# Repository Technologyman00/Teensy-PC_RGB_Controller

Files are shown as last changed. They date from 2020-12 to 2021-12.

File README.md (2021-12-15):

# Teensy-PC_RGB_Controller
 
The whole Idea behind this project was to create a much better RGB controller than the controllers or motherboard software I have seen. Currently It has already met that goal as it can play any pattern for many LEDs and up to individual 40 devices. I am still working on the user interface and many qualities of life things, but the main functionality does work. HOWEVER, it will need a PCB made to power all the LEDs as a Teensy cannot power that many safely.

## Features

- No Extra load on the CPU. The teensy has its own built in CPU that will handle all the commands to the ARGB devices.
- Store Loads of Patterns or Huge animations. The teensy uses an SD card to save and read all the patterns allowing for a huge number of patterns to be saved.
- Up to 40 ports. Most Controllers top out at a maximum of 4 ports. The teensy has 40! This allows each device to do its own individual pattern.
- Any pattern! There are no limitations on what can be displayed because it plays back frames allowing an almost infinite amount of customization. 
- Standard Plugs! This uses the regular 3 pin 5V ARGB connectors so any device with the same connector can be used!
- OPEN SOURCE! Are you a bit handier than most? You can change anything you would ever what about this project!

## Documentation
### Pattern Files

Description | Command | Argument 1 | Argument 2
------------ | -------------| ------------ | -------------|
Send RGB Command: | 0 | Port Number | Color Data |
Send HSV Command: | 1 | Port Number | Hue (2 Bytes) S (1 Byte) V (1 Byte)|
Change Frame Delay: | 2 | Delay (2 Bytes) | N/A |
Create Device/Change Length: | 3 | Port Number | Number of Pixels |
Start New Frame: | 4 | N/A | N/A | N/A |

- Port 13 is not accessable from the hardware as it has the status LED so it was intentionally skipped in the PCB design. 

- Color Data is a continuous set of the RGB or HSV values. It will be (3 * Number of Pixels in Device) bytes long. For example it would go (Red Byte)(Blue Byte)(Green Byte)(Red Byte)(Blue Byte)(Green Byte)... or (Hue Byte)(Saturation Byte)(Value Byte)(Hue Byte)(Saturation Byte)(Value Byte)... All these bytes are from 0-255 with no decimals, as bytes are. For hue, saturation, and value these are all scaled to their corrective values.

- The delay value is split into 2 different bytes to allow a delay between 0 and 65535ms or 65.5 seconds. This allows a great range between quick animations and still colors. This value does not matter so much for still colors as the pattern file will just start over once it reaches the end re-displaying the same color.

### Serial Commands

Description | Command | Argument 1 | Argument 2 | Argument 3 |
------------ | -------------| ------------ | -------------| -------------|
Play File on SD Card: | P | File Name | N/A | N/A |
Write File to SD Card: | W | File Name | Length to Read (4 Bytes) | File Data |
Delete File on SD Card: | X | File Name | N/A | N/A |
List Files on SD Card: | L | N/A | N/A | N/A |
Change Startup File: | S | File Name | N/A | N/A |
Display Frame: | D | RGB or HSV -> (0 or 1) | Port Number | Color Data |
New Device: | N | Port | Number of Pixels | N/A |
Restart Teensy: | R | N/A | N/A | N/A |
Check Teensy Tempature: | T | N/A | N/A | N/A |

- File Name requires the file type *"example.txt"*
- File Data follows the documentation as setup in pattern files
- Length to Read is split into 4 bytes to allow very large files to be transferred (~4.3 GB) (if larger than ~4.3 GB just put the file onto the SD card manually)
- Color Data also follows the documentation as shown in pattern files
- ***Deleting files will ask if "Are sure you want to delete this?" A response is needed of Y/N before it will continue. Everything is halted when this is prompted.***
- ***Showing a Frame will not return to normal file reading until an exit command of X is sent.***

### Startup Handler

On startup the teensy will first read the *startup.txt* file which should contain the name of the file and only the name of the file. If this file does not exist or the code is unhappy with what was entered it will delete the *startup.txt* file and replace it with a *startup.txt* file that will run the default pattern file. The default pattern file sets all 40 ports to display Green on 255 pixels on those ports. This should make it so that it is obvious that the Teensy is working. The *startup.txt* file can be changed by either editing the file in a text editor or by sending the S command over serial.

## Updates
6/6
Full Deployment!!!!!
Example 1: https://youtu.be/utrNA2Hu2Kg
Example 2: https://youtu.be/6SqUPKUgLiA

5/30 Version 2 of the PCB was ordered and should be arriving shortly. This new version is to fix the concerns with the previous version, as the size was quite large and there was a design error. Both should be fixed in this version. Pin 13 was also taken off of the available pins as it was decided that it should be used as a status LED and should remain off if used. 

3/14 PCB Came in had issues. The Output enable pin was grounded not powered, which means it was disabled not enabled. (Woops) A small soldered wire fixed that. 
First Test : https://youtu.be/IeGvDfm8C_M

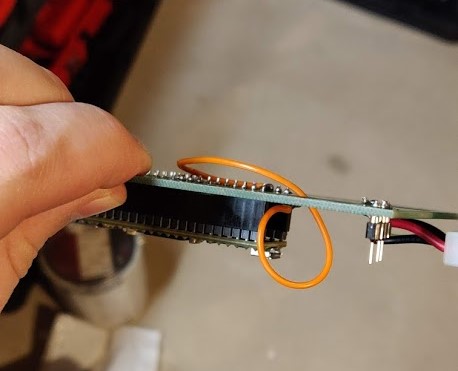
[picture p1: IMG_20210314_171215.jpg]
photo of wire added to PCB


## Limitations
#### Files
   - Limited to a File Name of 8 Characters
     - example1.txt is at the max length
   - Is not case-sensitive 
     - example1.txt == EXAMPLE1.txt
      
#### Max SD card size is 32 GB
   - There are some potential work arounds for larger SD cards
   
#### LED Devices can only be added not removed per a given reboot
   - I really cant imagine this being an issue for anyone, but I thought its important to note just incase.
   - If 40 devices are created then they cannot be removed until a reboot
   - All 40 devices will be written to until a reboot occurs

## To Do
- [ ] Create Pattern Designer
- [ ] Loop Commands inside Files?
- [ ] Command Files for other Files?
- [ ] Allow devices to be removed without reboot?

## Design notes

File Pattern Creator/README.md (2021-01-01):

# Pattern Creator is hosted in github pages.

https://technologyman00.github.io/Teensy-PC_RGB_Controller/

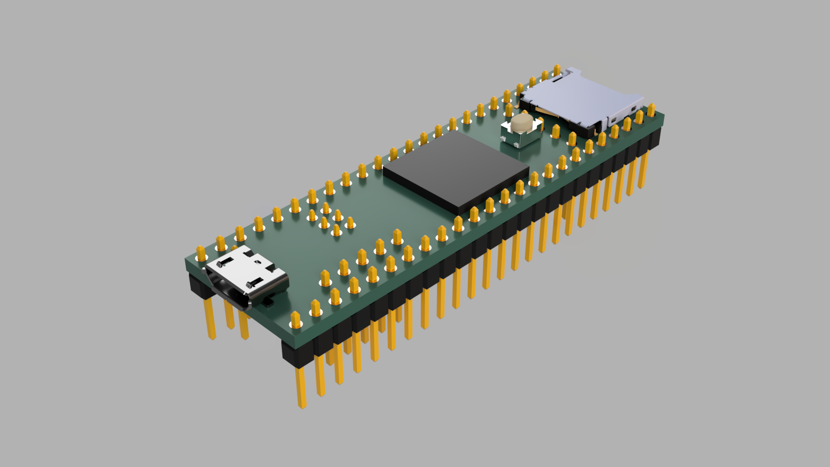
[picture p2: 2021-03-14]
2 PCB/CAD/teensy-4-1-development-board-1.snapshot.5/Teensy 4.1 (With Haeders).png

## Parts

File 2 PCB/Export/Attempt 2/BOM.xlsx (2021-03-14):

Comment | Designator | Footprint | LCSC Part #（optional）
Level Shift | U1, U2, U3, U4, U5 | SOP65P640X120-20N | TXS0108EPWR
10KΩ | R1 | R_0201_0603Metric | 0603WAF1002T5E

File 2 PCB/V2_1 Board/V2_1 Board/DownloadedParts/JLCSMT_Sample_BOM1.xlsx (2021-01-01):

Comment | Designator | Footprint | LCSC Part #（optional）
100uF | C1 | CASE-B_3528 | C16133
100nF | C2, C9, C10 | 0603_C | C14663
10uF | C3-5 | 1206_C | C13585
15KΩ | R5, R6 | 0603_R | C22809

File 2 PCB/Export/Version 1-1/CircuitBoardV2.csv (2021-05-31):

Comment | Designator | Footprint
TXS0108EPWR | U1 | TXS0108EPWR
TXS0108EPWR | U2 | TXS0108EPWR
TXS0108EPWR | U3 | TXS0108EPWR
TXS0108EPWR | U4 | TXS0108EPWR
TXS0108EPWR | U5 | TXS0108EPWR

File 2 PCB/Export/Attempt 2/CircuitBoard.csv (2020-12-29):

Id | Designator | Package | Quantity | Designation | Supplier and ref
1 | U5,U4,U3,U2,U1 | SOP65P640X120-20N | 5 | TXS0108EPWR
2 | R1 | R_0201_0603Metric | 1 | 10k
3 | JMolex1 | TE_MATE-N-LOK_350211-1_1x04_P5.08mm_Vertical | 1 | Conn_01x04_Male
4 | J42,J41,J40,J39,J38,J37,J36,J35,J34,J33,J32,J31,J30,J29,J28,J27,J26,J25,J24,J23,J20,J19,J18,J17,J16,J15,J14,J13,J12,J11,J10,J9,J8,J7,J6,J5,J4,J3,J2,J1 | FanPinHeader_1x04_P2.54mm_Vertical | 40 | Conn_01x04_Male
5 | J22,J21 | PinSocket_1x24_P2.54mm_Vertical | 2 | Conn_01x24_Female

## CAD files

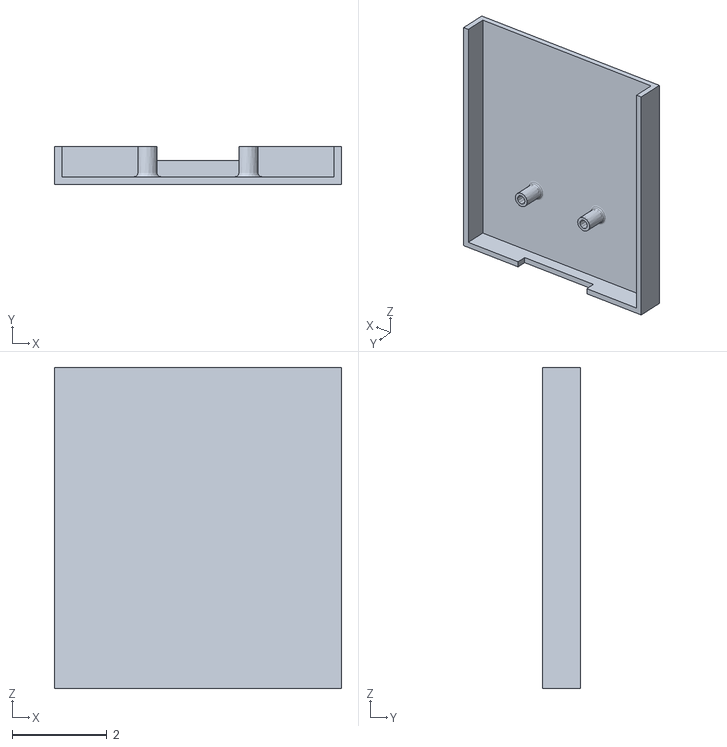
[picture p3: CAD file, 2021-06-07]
2 PCB/CAD/CaseHalfMolex.stl
6.07 x 0.794 x 6.78

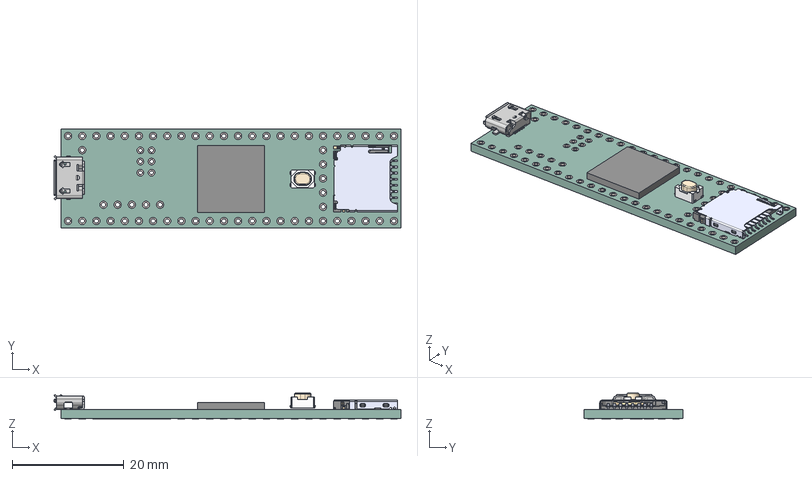
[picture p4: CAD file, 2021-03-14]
2 PCB/CAD/teensy-4-1-development-board-1.snapshot.5/Teensy 4.1 (Without Headers).step
62.2 x 17.8 x 4.62 mm
114-00841-68--3DModel-STEP-56544
MIMXRT1052CVJ5B
MicroUSB Molex 473460001
PTS810 SJK 250 SMTR LFS

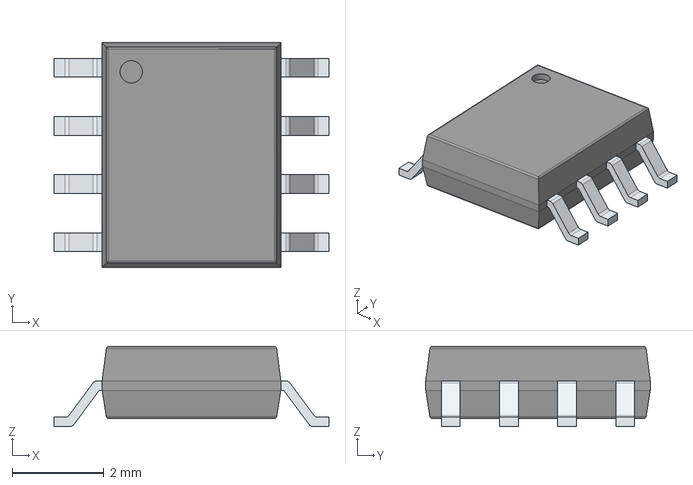
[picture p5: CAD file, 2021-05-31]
2 PCB/V2_1 Board/V2_1 Board/DownloadedParts/Molex/NE555DR.stp
6.00 x 4.90 x 1.75 mm
PinsArrayLR

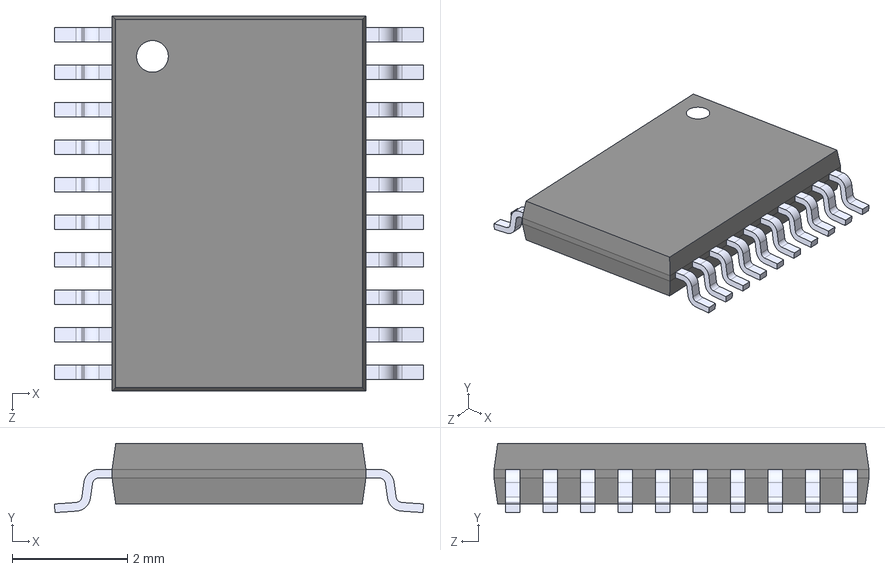
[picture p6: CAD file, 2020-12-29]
2 PCB/V2_1 Board/V2_1 Board/DownloadedParts/TXS0108EPWR/TXS0108EPWR.step
6.40 x 1.20 x 6.50 mm

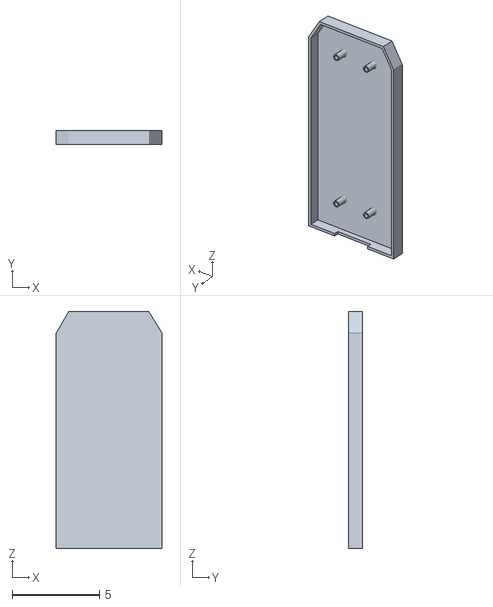
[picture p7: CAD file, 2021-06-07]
2 PCB/CAD/CaseBottomV2.stl
6.07 x 0.794 x 13.6

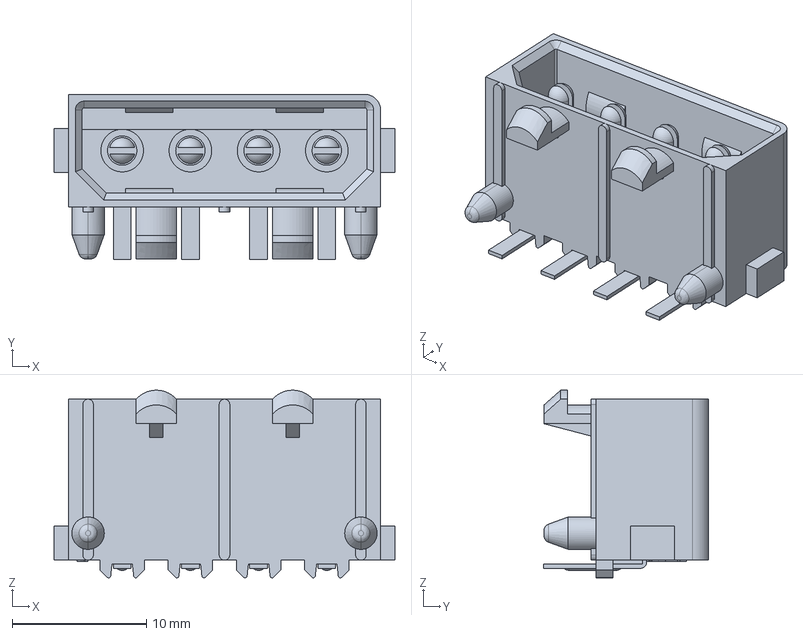
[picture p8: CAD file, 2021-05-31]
2 PCB/V2_1 Board/V2_1 Board/DownloadedParts/Molex/770846-1.stp
25.4 x 12.3 x 14.0 mm

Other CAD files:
2 PCB/CAD/CaseHalfFront.stl
2 PCB/CAD/BuiltV1.iam
2 PCB/CAD/COMPOUND.ipt
2 PCB/CAD/CaseBottomV2.ipt
2 PCB/CAD/CaseV1.ipt
2 PCB/CAD/CircuitBoard.iam
2 PCB/CAD/FanPinHeader_1x04_P2.54mm_Vertical.iam
2 PCB/CAD/MolexConnector.ipt
2 PCB/CAD/OldVersions/BuiltV1.0003.iam
2 PCB/CAD/OldVersions/CaseBottomV2.0002.ipt
2 PCB/CAD/OldVersions/CaseV1.0003.ipt
2 PCB/CAD/PinSocket_1x24_P2.54mm_Vertical.iam
2 PCB/CAD/R_0201_0603Metric.iam
2 PCB/CAD/SOLID.ipt
2 PCB/CAD/SOLID_1.ipt
2 PCB/CAD/SOLID_2.ipt
2 PCB/CAD/V2/COMPOUND.ipt
2 PCB/CAD/V2/CircuitBoardV2.iam
2 PCB/CAD/V2/FanPinHeader_1x04_P2.54mm_Vertical.iam
2 PCB/CAD/V2/PinSocket_1x24_P2.54mm_Vertical.iam
2 PCB/CAD/V2/R_0603_1608Metric.iam
2 PCB/CAD/V2/SOLID.ipt
2 PCB/CAD/V2/SOLID_1.ipt
2 PCB/CAD/V2/SOLID_2.ipt
2 PCB/CAD/V3/AssembledProduct.iam
2 PCB/CAD/V3/COMPOUND.ipt
2 PCB/CAD/V3/CircuitBoardV2.iam
2 PCB/CAD/V3/FanPinHeader_1x04_P2.54mm_Vertical.iam
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

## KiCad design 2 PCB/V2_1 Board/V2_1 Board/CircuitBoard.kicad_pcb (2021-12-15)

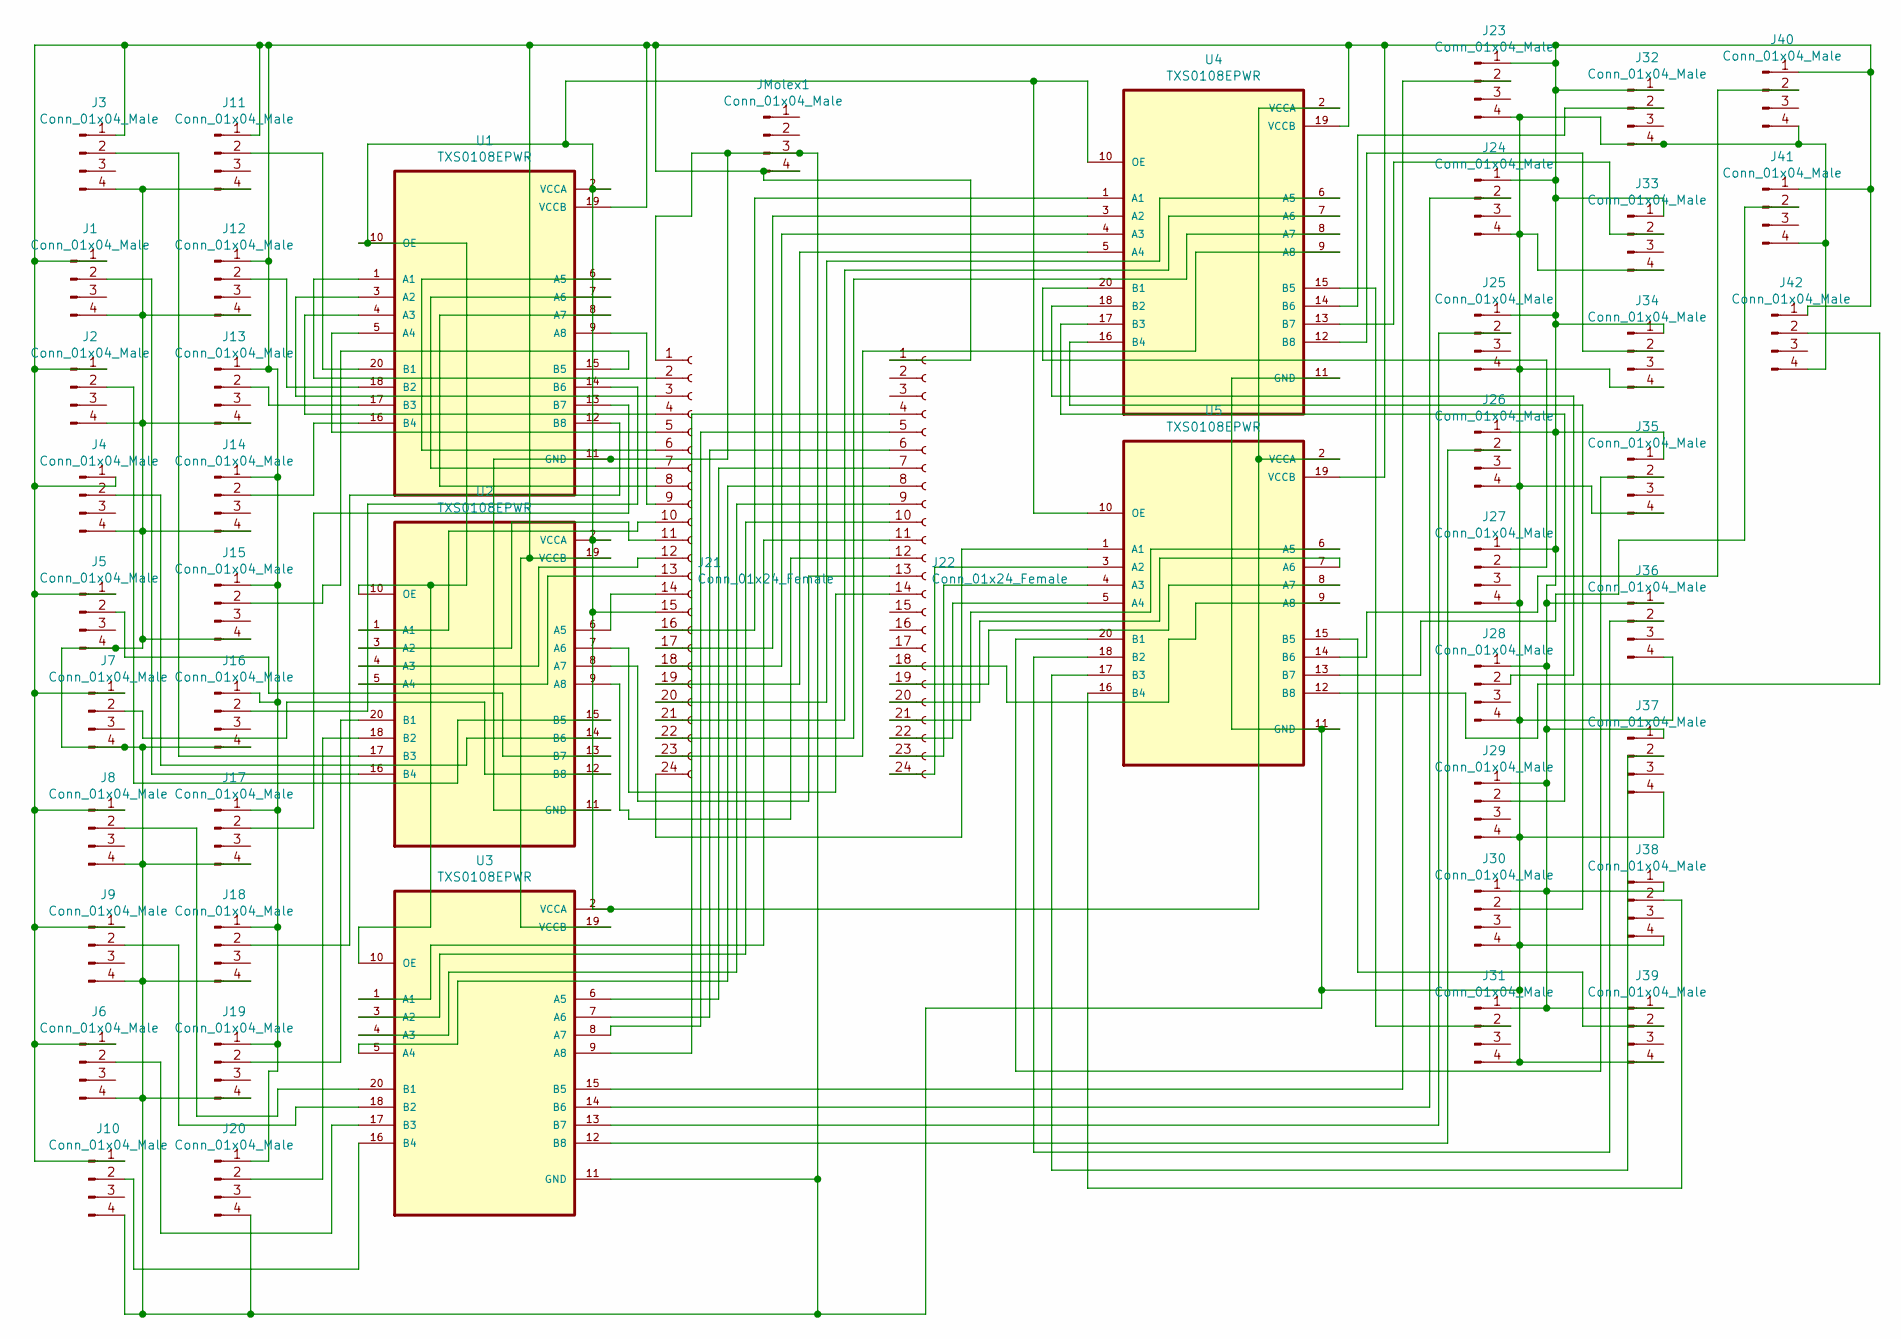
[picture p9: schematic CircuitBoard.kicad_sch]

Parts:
J1, J2, J3, J4, J5, J6, J7, J8, J9, J10, J11, J12, J13, J14, J15, J16, J17, J18, J19, J20, J23, J24, J25, J26, J27, J28, J29, J30, J31, J32, J33, J34, J35, J36, J37, J38, J39, J40, J41, J42: Conn_01x04_Male; FanPinHeader_1x04_P2.54mm_Vertical
J21, J22: Conn_01x24_Female; PinSocket_1x24_P2.54mm_Vertical
JMolex1: Conn_01x04_Male; 7708461
U1, U2, U3, U4, U5: TXS0108EPWR; SOP65P640X120-20N

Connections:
unnamed: J1.2, U2.16 (B4)
unnamed: J1.4, J2.4, J3.4, J4.4, J5.4, J6.4, J7.4, J8.4, J9.4, J10.4, J11.4, J12.4, J13.4, J14.4, J15.4, J16.4, J17.4, J18.4, J19.4, J20.4, J21.1, J23.4, J24.4, J25.4, J26.4, J27.4, J28.4, J29.4, J30.4, J31.4, J32.4, J33.4, J34.4, J35.4, J36.4, J37.4, J38.4, J39.4, J40.4, J41.4, J42.4, JMolex1.3, U1.11 (GND), U2.11 (GND), U3.11 (GND), U4.11 (GND), U5.11 (GND)
unnamed: J2.2, U2.15 (B5)
unnamed: J3.2, U2.17 (B3)
unnamed: J4.2, U2.14 (B6)
unnamed: J5.2, U2.13 (B7)
unnamed: J6.2, U3.17 (B3)
unnamed: J7.2, U2.12 (B8)
unnamed: J8.2, U3.20 (B1)
unnamed: J9.2, U3.18 (B2)
unnamed: J10.2, U3.16 (B4)
unnamed: J11.2, U1.20 (B1)
unnamed: J12.2, U1.18 (B2)
unnamed: J13.2, U1.17 (B3)
unnamed: J14.2, U1.16 (B4)
unnamed: J15.2, U1.15 (B5)
unnamed: J16.2, U1.14 (B6)
unnamed: J17.2, U1.13 (B7)
unnamed: J18.2, U1.12 (B8)
unnamed: J19.2, U2.20 (B1)
unnamed: J20.2, U2.18 (B2)
unnamed: J21.2, U1.1 (A1)
unnamed: J21.3, U1.3 (A2)
unnamed: J21.4, U1.4 (A3)
unnamed: J21.5, U1.5 (A4)
unnamed: J21.6, U1.6 (A5)
unnamed: J21.7, U1.7 (A6)
unnamed: J21.8, U1.8 (A7)
unnamed: J21.9, U1.9 (A8)
unnamed: J21.10, U2.1 (A1)
unnamed: J21.11, U2.3 (A2)
unnamed: J21.12, U2.4 (A3)
unnamed: J21.13, U2.5 (A4)
unnamed: J21.14, U2.6 (A5)
unnamed: J21.15, U1.2 (VCCA), U1.10 (OE), U2.2 (VCCA), U2.10 (OE), U3.2 (VCCA), U3.10 (OE), U4.2 (VCCA), U4.10 (OE), U5.2 (VCCA), U5.10 (OE)
unnamed: J21.16, U4.1 (A1)
unnamed: J21.17, U4.3 (A2)
unnamed: J21.18, U4.4 (A3)
unnamed: J21.19, U4.5 (A4)
unnamed: J21.20, U4.6 (A5)
unnamed: J21.21, U4.7 (A6)
unnamed: J21.22, U4.8 (A7)
unnamed: J21.23, U4.9 (A8)
unnamed: J21.24, U5.1 (A1)
unnamed: J22.4, U3.9 (A8)
unnamed: J22.5, U3.8 (A7)
unnamed: J22.6, U3.7 (A6)
unnamed: J22.7, U3.6 (A5)
unnamed: J22.8, U3.5 (A4)
unnamed: J22.9, U3.4 (A3)
unnamed: J22.10, U3.3 (A2)
unnamed: J22.11, U3.1 (A1)
unnamed: J22.12, U2.9 (A8)
unnamed: J22.13, U2.8 (A7)
unnamed: J22.14, U2.7 (A6)
unnamed: J22.18, U5.9 (A8)
unnamed: J22.19, U5.8 (A7)
unnamed: J22.20, U5.7 (A6)
unnamed: J22.21, U5.6 (A5)
unnamed: J22.22, U5.5 (A4)
unnamed: J22.23, U5.4 (A3)
unnamed: J22.24, U5.3 (A2)
unnamed: J23.2, U3.15 (B5)
unnamed: J24.2, U3.14 (B6)
unnamed: J25.2, U3.13 (B7)
unnamed: J26.2, U3.12 (B8)
unnamed: J27.2, U4.20 (B1)
unnamed: J28.2, U4.18 (B2)
unnamed: J29.2, U4.17 (B3)
unnamed: J30.2, U4.16 (B4)
unnamed: J31.2, U4.15 (B5)
unnamed: J32.2, U4.14 (B6)
unnamed: J33.2, U4.13 (B7)
unnamed: J34.2, U4.12 (B8)
unnamed: J35.2, U5.20 (B1)
unnamed: J36.2, U5.18 (B2)
unnamed: J37.2, U5.17 (B3)
unnamed: J38.2, U5.16 (B4)
unnamed: J39.2, U5.15 (B5)
unnamed: J40.2, U5.14 (B6)
unnamed: J41.2, U5.13 (B7)
unnamed: J42.2, U5.12 (B8)

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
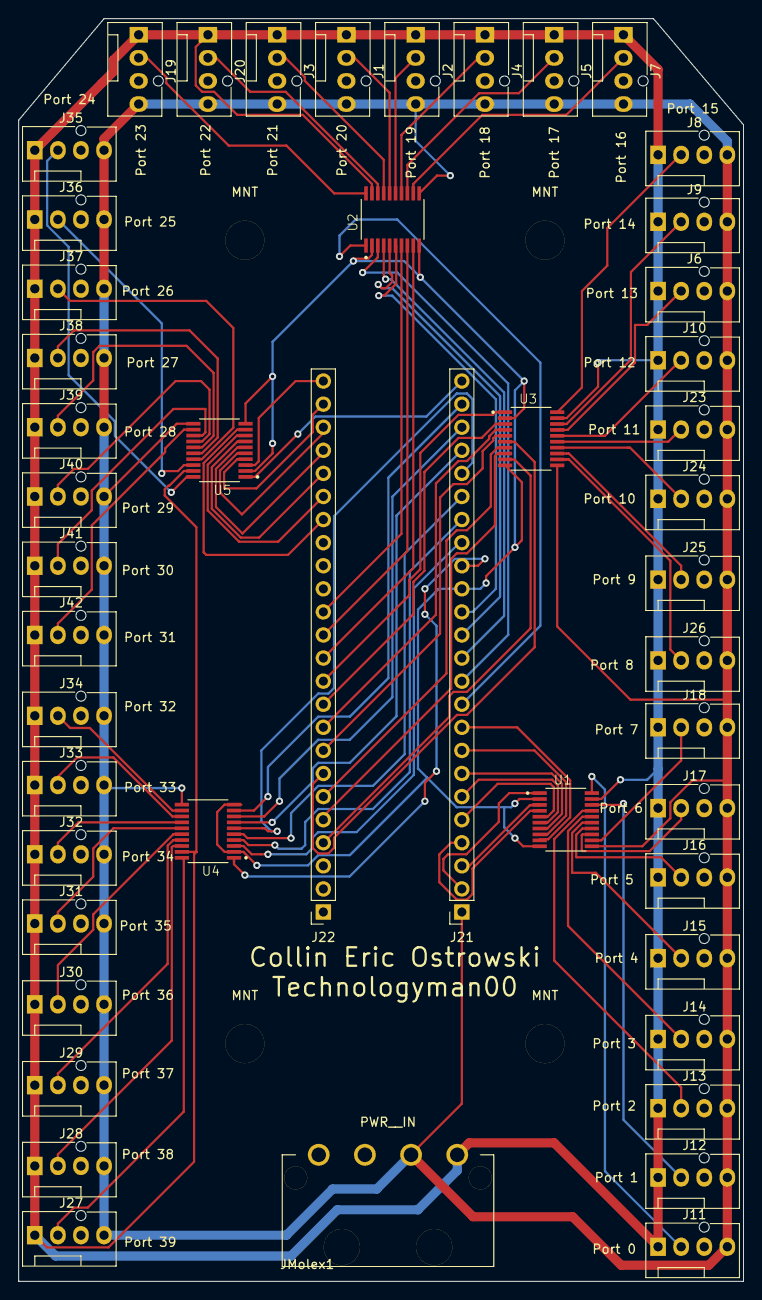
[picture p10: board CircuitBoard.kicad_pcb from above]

Board: 2 copper layers, 79.8 x 138.9 mm, 52 parts (0 on the bottom side), 83 nets.

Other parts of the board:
MNT: MountingHole_4.3mm_M4
MNT#2, MNT#3, MNT#4: MountingHole_4.3mm_M4

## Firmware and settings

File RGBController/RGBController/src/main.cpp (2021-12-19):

#include "Arduino.h"
#include <SD.h>
#include <SPI.h>
#include <math.h>

#include "global.h"
#include "functions.h"

#ifdef PARALLEL
  #include <OctoWS2811.h>
  // Any group of digital pins may be used
  // In Version 2 of the PCB pin 13 that drive the LED was removed as it should be controlled independently
  byte pinList[40] = {0, 1, 2, 3, 4, 5, 6, 7, 8, 9, 10, 11, 12, 14, 15, 16, 17, 18, 19, 20, 21, 22, 23, 24, 25, 26, 27, 28, 29, 30, 31, 32, 33, 34, 35, 36, 37, 38, 39, 40};

  // These buffers need to be large enough for all the pixels.
  // The total number of pixels is "ledsPerStrip * numPins".
  // Each pixel needs 3 bytes, so multiply by 3.  An "int" is
  // 4 bytes, so divide by 4.  The array is created using "int"
  // so the compiler will align it to 32 bit memory.
  DMAMEM int displayMemory[MAXPIXELS * MAXPORTS * 3 / 4];
  int drawingMemory[MAXPIXELS * MAXPORTS * 3 / 4];

  const int config = WS2811_GRB | WS2811_800kHz;

  OctoWS2811 leds(MAXPIXELS, displayMemory, drawingMemory, config, MAXPORTS, pinList);
#else
  #include <FastLED.h>
  CRGB Device[MAXPORTS][MAXPIXELS]; // Data for LEDS
#endif

byte deviceNumPixels[MAXPORTS]; // Number of Pixels per Device

//uint8_t buffer[BUFFSIZE] DMAMEM; // https://forum.pjrc.com/threads/66265-Fastest-way-to-transfer-data-to-from-Teensy-4-0-4-1-and-Windows-10
                                    //https://github.com/WMXZ-EU/MTP_t4

File frames; // Frames File Open
char selectedFile[255]; // Name of Frames file
char workingFile[255]; // Name of file being when using serial commands

// change this to match your SD shield or module;
// Arduino Ethernet shield: pin 4
// Adafruit SD shields and modules: pin 10
// Sparkfun SD shield: pin 8
// Teensy audio board: pin 10
// Teensy 3.5 & 3.6 & 4.1 on-board: BUILTIN_SDCARD
// Wiz820+SD board: pin 4
// Teensy 2.0: pin 0
// Teensy++ 2.0: pin 20
const int chipSelect = BUILTIN_SDCARD;

unsigned int delayval = 1000; // Time (in milliseconds) to pause between pixels
const unsigned int errorDelayVal = 1000; // Time to pause between alerting errors for opening files
const unsigned int delayStep = 1; // Time to pause between checking for Serial Commands inside Smart Delay

byte red = 0; // Temp Storage for Red Part of LED
byte green = 0; // Temp Storage for Green Part of LED
byte blue = 0; // Temp Storage for Blue Part of LED

unsigned int hue = 0; // Temp Storage for Hue Value
byte sat = 0; // Temp Storage for Saturation Value
byte value = 0; // Temp Storage for Value Value

byte commandSelect = 255; // Selected Command from File
byte port = 255; // Selected Port
int pixelsCount = 0; // Number of Pixels as Pulled from deviceNumPixels
int pixelsStart = 0;

unsigned long frameStartTime = 0; // Time when frame started
unsigned long currentTime = 0; // Time when frame ended

char serialCommand = 'A'; // Command Char from Serial
int lengthToRead = 0; // length to Read from Serial for file transfer

int badFrames = 0; // Count of Bad Frames gets reset when displayed to user
int framesPassed = 0; // Count of Frames Get Reset when reaches numbOfFramesTillAlert
const int numbOfFramesTillAlert = 10; // Frames till alerting user how many bad frames passed

bool forceNewFile = false; // If a new file is forced

const int numbOfLoopsTillSerialCheck = 10; // Number of loops till checking for serial commands
int loopCount = 0; // Count of Loops passed Gets Reset when reaches numbOfLoopsTillSerialCheck

const char startFileName[12] = "startup.txt";
const char defaultFileName[12] = "default.txt"; 

int statusLED = 13; // LED on the Teensy

bool sleeping = false;

void setup(){

  for(int i=0; i < MAXPORTS; i++){
    deviceNumPixels[i] = 0; // Initalizes the Array for Error Checking later
  }

  // Open serial communications and wait for port to open:
  Serial.begin(9600); // Does not need to set a speed but is written for conventions
  Serial.setTimeout(0); // Makes it not pause after reading in the Serial Commands

  //memset(buffer, 0x44,BUFFSIZE); // Increase Serial Buffer Size

  delay(10); // Used In Example before SD card. I assume to allow SD to initalize??

  if (!SD.begin(chipSelect)) {
    Serial.println("initialization failed!");
    return;
  }

  //Set Default file
  //charArrayWriter(selectedFile, (char*) "frames4.txt"); // Old way with a hardcoded default file name
  initalizeLEDCommands(); //Reads a startup file first to know which pattern to open by default
  #ifdef PARALLEL
    leds.begin();
  #endif

  pinMode(statusLED, OUTPUT); // Set the status LED to be an output.
  digitalWrite(statusLED, LOW); // Annoying for it to always be on because there is an external power source. 

  tempmon_init();

  frameStartTime = millis(); // Start the First Frame time
}

void loop(){
	// re-open the file for reading:
  frames = SD.open(selectedFile);
  if(frames){
    // read from the file until there's nothing else in it:
    while(frames.available()){

      loopCount++; // Increment LoopCount
      if(loopCount >= numbOfLoopsTillSerialCheck){ // Check if time to check serial updates
        getSerialUpdates(); // Check if there is a Serial Command to handle
        loopCount = 0;
      }
      switch (frames.read()){ // Read Command
        
        // RGB Color Sending
        case 0:{
          port = frames.read();
          pixelsCount = deviceNumPixels[port];
          if(pixelsCount == 0){ // No device should have 0 pixels
            Serial.print("Device: ");
            Serial.print(port);
            Serial.println(" not setup!");
          }
          else { // Update Pixels
            pixelsStart = GetLEDStart(port);
            pixelsCount += pixelsStart;
            for(int i=pixelsStart; i < pixelsCount; i++){
              red = frames.read(); // Read Red Val
              green = frames.read(); // Read Green Val
              blue = frames.read();  // Read Blue Val

              #ifdef PARALLEL
                leds.setPixel(i, red, green, blue);
              #else
                Device[port][i] = CRGB(-red+255, -green+255, -blue+255); // Update RAM for Pixels Info
              #endif

              if(forceNewFile){ // Break for loop if Requested by User
                break; // Causes for loop escape
              }
            }
          }
          break;
        }
  
        // HSV Color Sending
        case 1:{
          port = frames.read();
          pixelsCount = deviceNumPixels[port];
          if(pixelsCount == 0){ // No device should have 0 pixels
            Serial.print("Device: ");
            Serial.print(port);
            Serial.println(" not setup!");
          }
          else { // Update Pixels
            pixelsStart = GetLEDStart(port);
            pixelsCount += pixelsStart;
            for(int i=pixelsStart; i < pixelsCount; i++){

              hue = (unsigned int) frames.read(); // Read First Byte of Hue
              hue = hue << 8; // Shift up the first byte
              hue += (unsigned int) frames.read(); // Read Second Byte of Hue

              //hue = frames.read(); // Read Hue Val
              sat = frames.read(); // Read Saturation Val
              value = frames.read();  // Read Value Val
              HSVtoRGB(hue, sat, value); // Convert HSV to RGB // Updates Global RGB values

              #ifdef PARALLEL
                leds.setPixel(i, red, green, blue);
              #else
                Device[port][i] = CRGB(-red+255, -green+255, -blue+255); // Update RAM for Pixels Info
              #endif

              if(forceNewFile){ // Break for loop if Requested by User
                break; // Causes for loop escape
              }
            }
          }
          break;
        }
        // Change Delay between
        case 2:{
          delayval = (unsigned int) frames.read(); // Makes the first byte the Delay time
          delayval = delayval << 8; // Shift up the first byte
          delayval += (unsigned int) frames.read(); // Adds the second byte to the Delay time
          break;
        }
  
        // Create New Device
        case 3:{ // Create New Device
          port = frames.read(); // Read Device Port
          pixelsCount = frames.read(); // Read How Many Pixels that device has
  
          CreateLedDevice(port, pixelsCount); // Creates the Device
          
          deviceNumPixels[port] = pixelsCount; // Record how many pixels
          break;
        }
        
        // Start and/or Wait for Next Frame
        case 4:{
          #ifdef PARALLEL
                leds.show();
                //while (leds.busy()){ // Wait until all sending has completed
                //  smartDelay(1);
                //}
          #else
                FastLED.show(); //Send the Updated Pixel Data to the Devices
          #endif

          currentTime = millis(); // Update the Current Time
          framesPassed++; // Increment Frame Counter
          if((currentTime - frameStartTime) < delayval){ // See if the time took less than it should for a single frame.
            smartDelay(delayval - (currentTime - frameStartTime)); // Wait the remaning time and Check for Serial Commands
          }
          else{ 
            badFrames++; // Increment bad Frame Counter
          }
          if(framesPassed >= numbOfFramesTillAlert){ // Check if correct number of Frames have passed.
            framesPassed = 0; // Reset Frame Counter.
            if(badFrames > 0){ // Check if number of bad frames is greater than 0.
              // Alert User that it takes too long to update frames if done constantly
                Serial.print(badFrames);
                Serial.println(" FRAME(S) TAKING TOO LONG TO DRAW!!!");
                
                badFrames = 0; // Reset Frame counter 
            }
          }
          frameStartTime = millis(); // Update Frame Start Time
          break;
        }
      }
      if(forceNewFile){ // Break While loop if Requested by User
        forceNewFile = false; // Reset force new file bool
        break; // Causes while loop escape and to close the currently open file to either refresh the file or open a new file.
      }
    }
    // close the file:
    frames.close();
  } 
  else {
   // // if the file didn't open, print an error:
   Serial.print("error opening ");
   Serial.println(selectedFile);
   smartDelay(errorDelayVal); // Wait as to not spam console and Check for Serial Commands
  }
}

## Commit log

2020-12-21 Writing File over Serial Added but not working
    Writing File over Serial Added but not working. Seems to crash after creating the file because if tried to create the same file name it will cause it to alert properly to saying the file already exists.
    [RGBController.ino]
2020-12-23 Fixing Some Serial Issues
    [FileLengthTest.ino, RGBController.ino, SendFile.py]
2020-12-23 VSCode Transfer Complete
    Arduino's IDE was getting crouded and annoying, so moving to VSCode for a better IDE and to help with easier Multi-file coding. It also makes C++ a bit more true to form instead of the Arduino flavor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
2020-12-24 Added Live Frame Sending
    Live Frame Sending added for displaying temp. It does not work 100% properly yet.
    [LiveFrame.py, serialControl.cpp]
2020-12-24 Changed how Delaying between frames works
    Old Delays used to just delay between frames. This is bad because if told to delay for a long time then serial commands wont work until after delay has happend. Which will be really really really bad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
2020-12-25 Added Restart ability to Teensy and Started work on Desktop Apps
    The Teensy can now be restarted with the serial command "r" and there is now an .exe for sending this command. It does only work for it being on COM4 however. This will need to be updated.
    [PowerBoard.kicad_pcb, PowerBoard.sch]
2020-12-25 Changed Startup behavoir
    The Teensy will now create a startup.txt where it will store the name of the file to play when it starts up. If that file does not exist it will create it and create a default pattern to play.
2020-12-26 Bug Fixes and More Desktop App Features
    Fixed some bugs with switching to a different file to play and fixed a bug where issues with the startup file would not cause the default file to play. The desktop apps can now send commands to play files and commands to change the on startup file.
    [main.cpp, serialControl.cpp]
2020-12-26 Added creating new devices over serial and now allows any case for Serial commands
2020-12-27 Added FindTeensy.exe
    Created a program to find the connected teensy. This will be incorperated into the other programs for sending data to the teensy.
2020-12-29 Work Done on PCB and Added Automatic Port Finding
    Work Done on PCB. It is pretty terrible, but it is being reviewed by a EE friend of mine. Added Automatic Port Finding, for the very likely chance the teensy isnt on COM4
    [CircuitBoard-B_Cu.gbr, CircuitBoard-B_Mask.gbr, CircuitBoard-B_Paste.gbr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]
2021-01-01 Added Parallel LEDs Commands and worked on Circuit Board
    Parallel LED Commands allow for sigificantly faster data sending to LEDs and Circuit board is mostly finalized and was reviewed and confirmed to be good.
    [BOM.xlsx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]
2021-01-03 Fixed how Includes are managed
    Changed includes to only import OctoWS2811 for parallel and only FastLED for non parallel.
    [main.cpp, serialControl.cpp]
2021-03-14 Production PCB Added
    Production PCB Added it was noticed since prodution there is an issue with the PCB that needs to be addressed in a future update. For now it can be fixed mostly by ripping the resistor off the board. Ideally then a wire will be soldered in its place to 3.3V
    [114-00841-68--3DModel-STEP-56544 v1.ipt, BOM.xlsx, BuiltV1.0003.iam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]
2021-03-21 PCB fix
2021-05-31 PCB V2 & Case Work & Code Updates
    PCB Version 2 started and completed. This makes it smaller and should fix the issues with having to solder a patch wire to the board. It also makes pin 13 no longer used for controlling the connected RGB components as it should not glow constantly which could disrupt RGB patterns. The new PCB also uses a much better mounting system for the Molex power connector. It also increased the trace width for the power traces to increase the current capabilities. As well a new case was started for covering the PCB inside a computer. Lastly, the Default pattern was bug fixed to no longer have issues with the MAXPIXELS constant being under 255. It also reflects the PCB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
    [770846-1.stp, AssembledProduct.0001.iam, AssembledProduct.iam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]
2021-06-07 New Patterns and New Features and Deployment
    Some changes as it was fully deployed and I was able to test everything. I was concerned about the temperature of the teensy so I added another serial command to check the internal temperature of the teensy. I was also testing out a ton of patterns major trial and error.
    [770846-1.stp, CaseBottomV2.0001.ipt, CaseBottomV2.0002.ipt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]
2021-12-15 Hue resolution changed to two bytes
    Hue resolution changed to two bytes. I wasn't happy how obvious it was when the color changed for hue, so I made it 2 bytes for significantly higher resolution. I also recently got some RGB ram, so I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
    [770846-1.stp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]
